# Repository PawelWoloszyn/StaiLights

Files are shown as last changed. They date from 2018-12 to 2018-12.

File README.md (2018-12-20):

Stairs is electronics and programming project of controlling stair lights (led strips attached to bottom side of each step) using arduino nano and tlc5940.
Project contains both electronic schematics and code needed to create such controller, mind that I'm neither professional electronics
circuit designer nor software developer therefore both code and schematics might be adjusted to benefit your own implication.

Right now the device is under development and will remain in this state until implemented in real which is going to allow it's
long term testing and proof it's reliability. In this moment it only serves presentation purpose.

How does it work???
Arduino Nano controlls two TLC5940 controllers which are basicaly 16 channel PWM controller (each chip). PWM signal is inverted and used to drive MOSFET tranzistors which are responsible for regulating the current running through led strips. In order to automate this device DS1307 RTC is used. Thanks to this, device will only be switched on within specified period of time which is calculated by Dusk2Dawn library, lights are triggered by two PIR sensors one upstairs and one downstairs but there are plenty enough spare pins on Arduino nano to use other type of sesnor. Project also allows to externaly regulate device's parameters using microswitch buttons and potentiometer. 

Questions that might bother you:

* What do you need for logical inverters?
- TLC5940 cannot be connected directly to MOSFETS in this project due to it's 0 based logic, of course they could be driven with inverted logic but because of the way tlc functions, you wouldn't be able to completely shut down the lights.

* On schematic you started connecting TLC pins starting from output 2 not 0 why?
- It's because I bought one chip from second hand with one pin missing. Therefore I skipped pin0 and pin1(missing).

Future improvements:
* Definitely chaging DS1307 to DS3231 in order to gain benefits of having alarm clock function in real time clock, which could later on be used to     wake up arduino from sleep mode.
* Reworking board design to decrease it's dimensions, would probably make a 2 sided SMD PCB.

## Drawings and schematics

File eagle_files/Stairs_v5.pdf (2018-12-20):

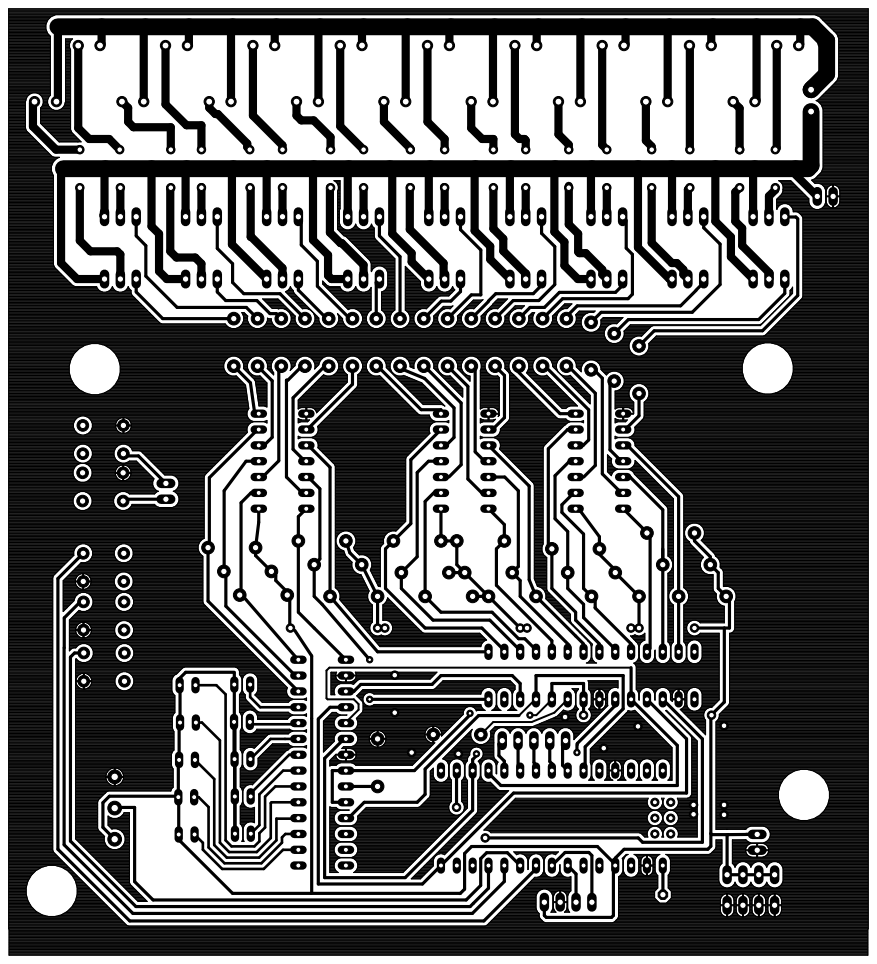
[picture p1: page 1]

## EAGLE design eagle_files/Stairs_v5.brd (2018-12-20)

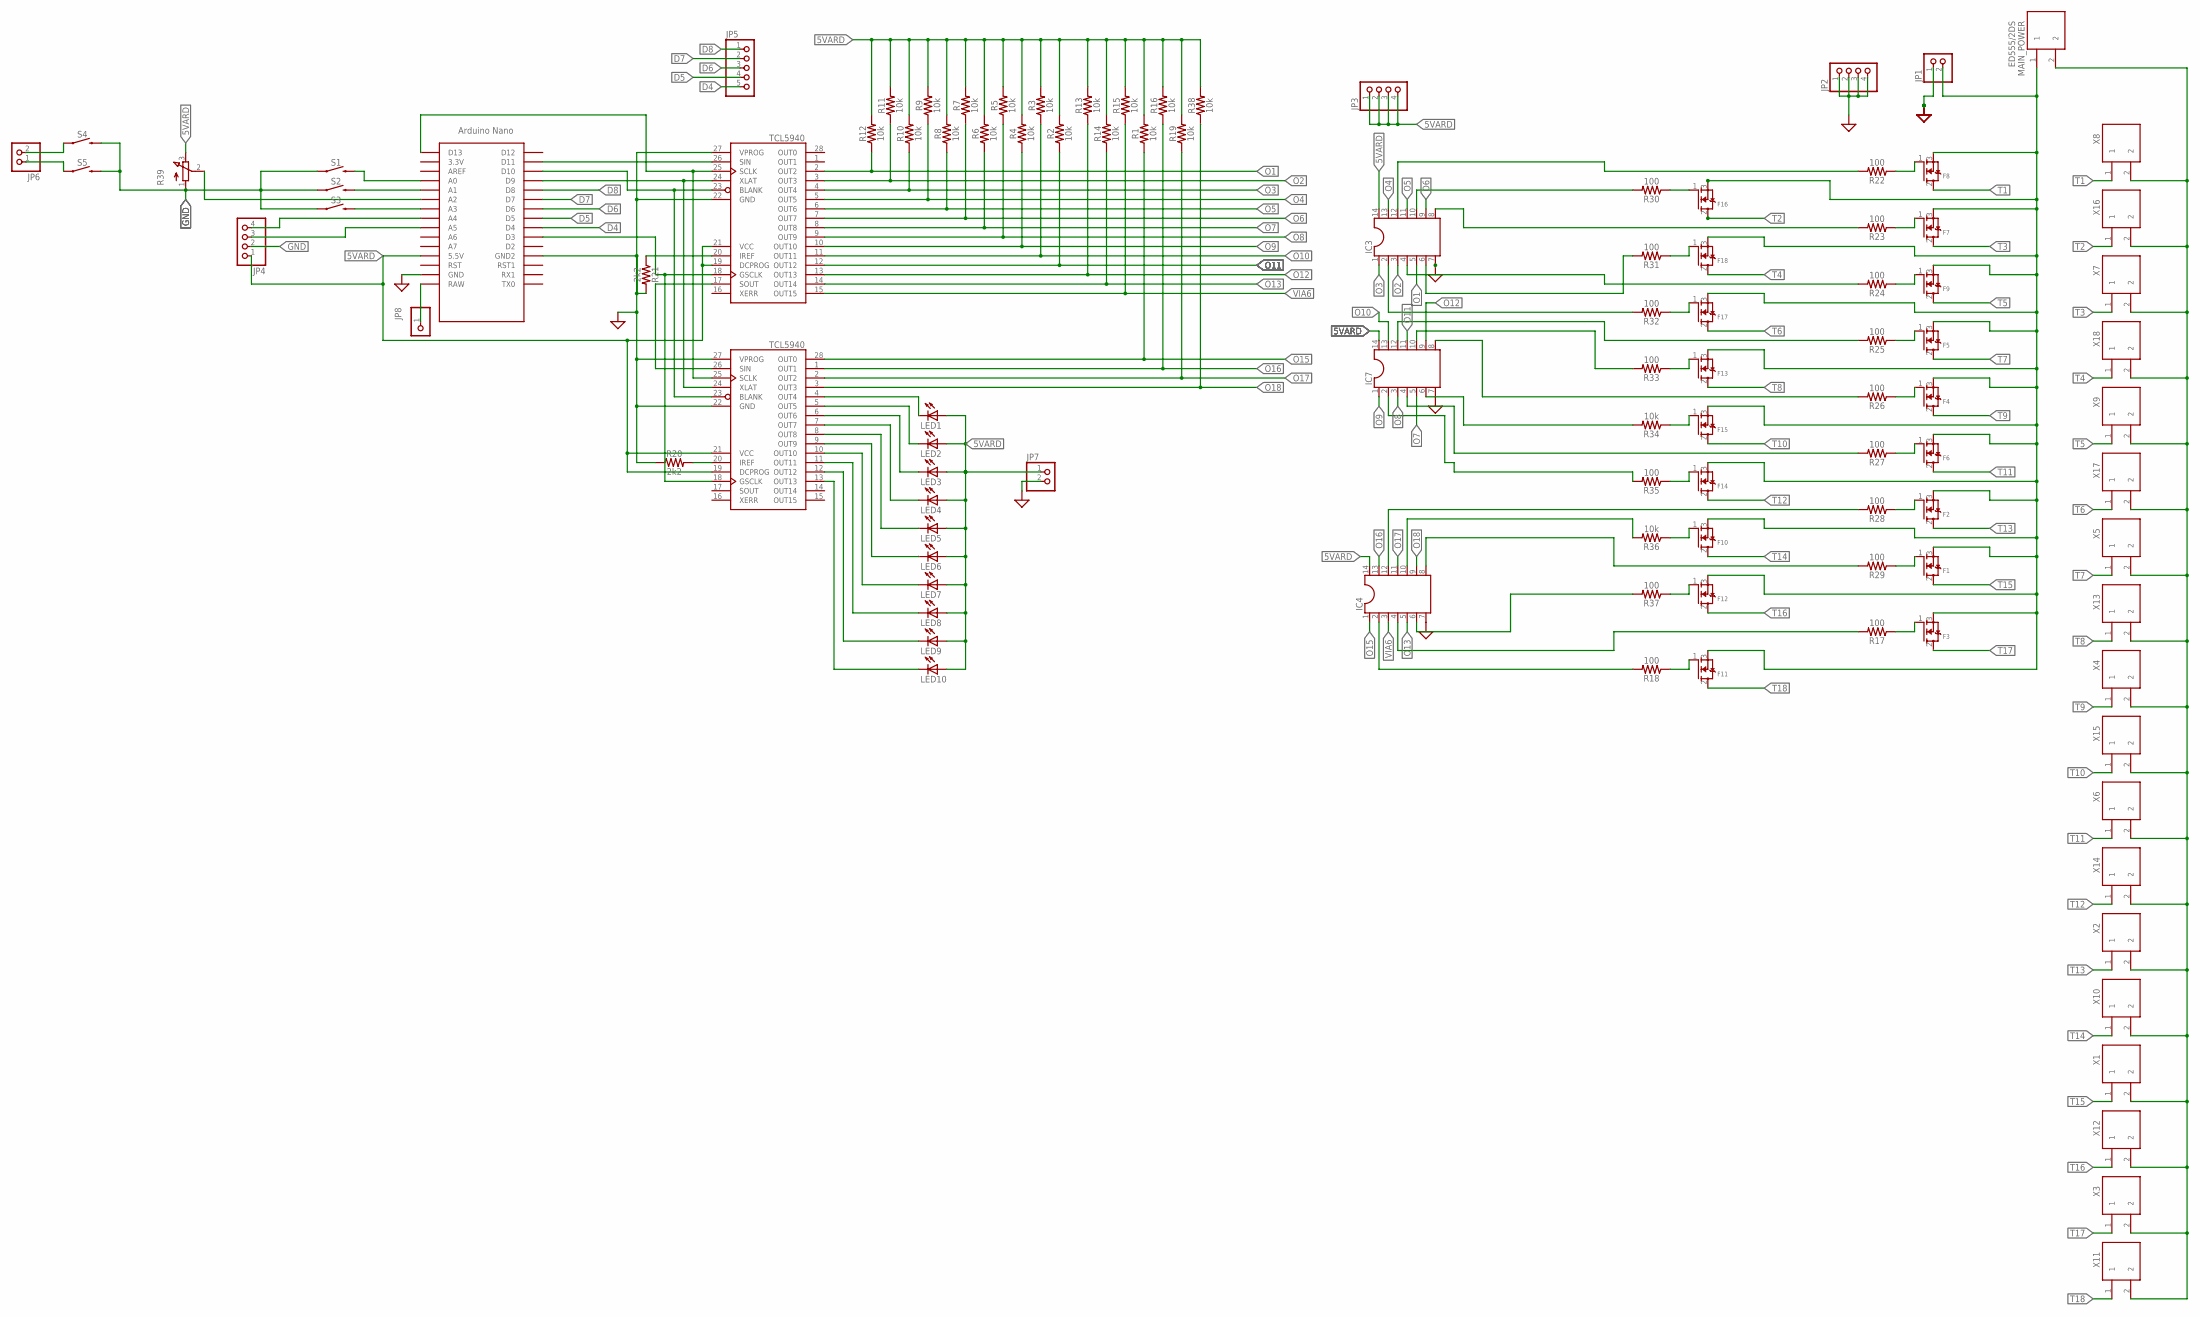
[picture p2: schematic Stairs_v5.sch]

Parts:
F1, F2, F3, F4, F5, F6, F7, F8, F9, F10, F11, F12, F13, F14, F15, F16, F17, F18: MOSFET-NGDS_TO220V; TO220V
IC1, IC2: TCL5940; DIP28
IC3, IC4, IC7: DIL14S; SOCKET-14
JP1, JP6, JP7: PINHD-1X2; 1X02
JP2, JP3, JP4: PINHD-1X4; 1X04
JP5: PINHD-1X5; 1X05
JP8: PINHD-1X1; 1X01
LED1, LED2, LED3, LED4, LED5, LED6, LED7, LED8, LED9, LED10: LEDSFH482; SFH482
MAIN_POWER: ED555/2DS
R1, R2, R3, R4, R5, R6, R7, R8, R9, R10, R11, R12, R13, R14, R15, R16, R19, R34, R36, R38: 10k; AXIAL-0.3-KIT
R17, R18, R22, R23, R24, R25, R26, R27, R28, R29, R30, R31, R32, R33, R35, R37: 100; AXIAL-0.3-KIT
R20, R21: 2k2; AXIAL-0.3-KIT
R39: 3RP/1610N
S1, S2, S3, S4, S5: MOMENTARY-SWITCH-SPST-PTH-6.0MM; TACTILE_SWITCH_PTH_6.0MM
U$1: NANO
X1, X2, X3, X4, X5, X6, X7, X8, X9, X10, X11, X12, X13, X14, X15, X16, X17, X18: ED555/2DS

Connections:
5VARD: IC1.19 (DCPROG), IC1.21 (VCC), IC2.19 (DCPROG), IC2.21 (VCC), IC3.14, IC4.14, IC7.14, JP3.1, JP3.2, JP3.3, JP3.4, JP4.1, JP7.1, LED1.A, LED2.A, LED3.A, LED4.A, LED5.A, LED6.A, LED7.A, LED8.A, LED9.A, LED10.A, R1.P$2 (2), R2.P$2 (2), R3.P$2 (2), R4.P$2 (2), R5.P$2 (2), R6.P$2 (2), R7.P$2 (2), R8.P$2 (2), R9.P$2 (2), R10.P$2 (2), R11.P$2 (2), R12.P$2 (2), R13.P$2 (2), R14.P$2 (2), R15.P$2 (2), R16.P$2 (2), R19.P$2 (2), R38.P$2 (2), R39.3 (E), U$1.5V (5.5V)
D4: JP5.5, U$1.D4
D5: JP5.4, U$1.D5
D6: JP5.3, U$1.D6
D7: JP5.2, U$1.D7
D8: JP5.1, U$1.D8
GND: IC1.22 (GND), IC1.27 (VPROG), IC2.22 (GND), IC2.27 (VPROG), IC3.7, IC4.7, IC7.7, JP1.1, JP2.1, JP2.2, JP2.3, JP2.4, JP4.2, JP7.2, R20.P$1 (1), R21.P$2 (2), R39.1 (A), S1.1, S2.1, S3.1, S4.3 (2), S5.3 (2), U$1.GND, U$1.GND1 (GND2)
unnamed: IC2.4 (OUT4), LED1.K (C)
unnamed: JP8.1, U$1.RAW
unnamed: IC1.25 (SCLK), IC2.25 (SCLK), U$1.D13
unnamed: IC1.24 (XLAT), IC2.24 (XLAT), U$1.D9
unnamed: IC2.5 (OUT5), LED2.K (C)
unnamed: JP6.2, S4.1
unnamed: S1.3 (2), U$1.A0
unnamed: IC1.17 (SOUT), IC2.26 (SIN)
unnamed: IC1.20 (IREF), R21.P$1 (1)
unnamed: IC2.20 (IREF), R20.P$2 (2)
unnamed: F7.1 (G), R23.P$1 (1)
unnamed: IC1.18 (GSCLK), IC2.18 (GSCLK), U$1.D3
unnamed: S2.3 (2), U$1.A1
unnamed: R39.2 (S), U$1.A2
unnamed: F9.1 (G), R24.P$1 (1)
unnamed: S3.3 (2), U$1.A3
unnamed: JP4.4, U$1.A4
unnamed: F5.1 (G), R25.P$1 (1)
unnamed: JP4.3, U$1.A5
unnamed: F4.1 (G), R26.P$1 (1)
unnamed: JP6.1, S5.1
unnamed: F8.1 (G), R22.P$1 (1)
unnamed: IC2.6 (OUT6), LED3.K (C)
unnamed: F6.1 (G), R27.P$1 (1)
unnamed: IC2.7 (OUT7), LED4.K (C)
unnamed: IC2.8 (OUT8), LED5.K (C)
unnamed: F2.1 (G), R28.P$1 (1)
unnamed: IC2.9 (OUT9), LED6.K (C)
unnamed: IC2.10 (OUT10), LED7.K (C)
unnamed: F1.1 (G), R29.P$1 (1)
unnamed: IC2.11 (OUT11), LED8.K (C)
unnamed: IC2.12 (OUT12), LED9.K (C)
unnamed: IC2.13 (OUT13), LED10.K (C)
unnamed: F16.1 (G), R30.P$1 (1)
unnamed: F18.1 (G), R31.P$1 (1)
unnamed: F17.1 (G), R32.P$1 (1)
unnamed: F13.1 (G), R33.P$1 (1)
unnamed: F15.1 (G), R34.P$1 (1)
unnamed: F14.1 (G), R35.P$1 (1)
unnamed: F10.1 (G), R36.P$1 (1)
unnamed: F12.1 (G), R37.P$1 (1)
unnamed: IC3.12, R22.P$2 (2)
unnamed: IC3.8, R23.P$2 (2)
unnamed: IC3.4, R24.P$2 (2)
unnamed: IC7.10, R33.P$2 (2)
unnamed: IC3.10, R30.P$2 (2)
unnamed: IC3.6, R31.P$2 (2)
unnamed: IC3.2, R32.P$2 (2)
unnamed: IC7.12, R25.P$2 (2)
unnamed: IC7.8, R26.P$2 (2)
unnamed: IC7.4, R27.P$2 (2)
unnamed: IC4.12, R28.P$2 (2)
unnamed: IC4.8, R29.P$2 (2)
unnamed: IC7.6, R34.P$2 (2)
unnamed: IC4.10, R36.P$2 (2)
unnamed: IC7.2, R35.P$2 (2)
unnamed: IC4.6, R37.P$2 (2)
unnamed: F3.1 (G), R17.P$1 (1)
unnamed: IC4.4, R17.P$2 (2)
unnamed: F11.1 (G), R18.P$1 (1)
unnamed: IC4.2, R18.P$2 (2)
O1: IC1.2 (OUT2), IC3.5, R12.P$1 (1)
O2: IC1.3 (OUT3), IC3.3, R11.P$1 (1)
O3: IC1.4 (OUT4), IC3.1, R10.P$1 (1)
O4: IC1.5 (OUT5), IC3.13, R9.P$1 (1)
O5: IC1.6 (OUT6), IC3.11, R8.P$1 (1)
O6: IC1.7 (OUT7), IC3.9, R7.P$1 (1)
O7: IC1.8 (OUT8), IC7.5, R6.P$1 (1)
O8: IC1.9 (OUT9), IC7.3, R5.P$1 (1)
O9: IC1.10 (OUT10), IC7.1, R4.P$1 (1)
O10: IC1.11 (OUT11), IC7.13, R3.P$1 (1)
O11: IC1.12 (OUT12), IC7.11, R2.P$1 (1)
O12: IC1.13 (OUT13), IC7.9, R13.P$1 (1)
O13: IC1.14 (OUT14), IC4.5, R14.P$1 (1)
O15: IC2.28 (OUT0), IC4.1, R1.P$1 (1)
O16: IC2.1 (OUT1), IC4.13, R16.P$1 (1)
O17: IC2.2 (OUT2), IC4.11, R19.P$1 (1)
O18: IC2.3 (OUT3), IC4.9, R38.P$1 (1)
POWER+: MAIN_POWER.2, X1.2, X2.2, X3.2, X4.2, X5.2, X6.2, X7.2, X8.2, X9.2, X10.2, X11.2, X12.2, X13.2, X14.2, X15.2, X16.2, X17.2, X18.2
POWER-: F1.3 (S), F2.3 (S), F3.3 (S), F4.3 (S), F5.3 (S), F6.3 (S), F7.3 (S), F8.3 (S), F9.3 (S), F10.3 (S), F11.3 (S), F12.3 (S), F13.3 (S), F14.3 (S), F15.3 (S), F16.3 (S), F17.3 (S), F18.3 (S), JP1.2, MAIN_POWER.1
T1: F8.2 (D), X8.1
T2: F16.2 (D), X16.1
T3: F7.2 (D), X7.1
T4: F18.2 (D), X18.1
T5: F9.2 (D), X9.1
T6: F17.2 (D), X17.1
T7: F5.2 (D), X5.1
T8: F13.2 (D), X13.1
T9: F4.2 (D), X4.1
T10: F15.2 (D), X15.1
T11: F6.2 (D), X6.1
T12: F14.2 (D), X14.1
T13: F2.2 (D), X2.1
T14: F10.2 (D), X10.1
T15: F1.2 (D), X1.1
T16: F12.2 (D), X12.1
T17: F3.2 (D), X3.1
T18: F11.2 (D), X11.1
VIA4: IC1.26 (SIN), U$1.D11
VIA6: IC1.15 (OUT15), IC4.3, R15.P$1 (1)
VIAXX: IC1.23 (BLANK), IC2.23 (BLANK), U$1.D10

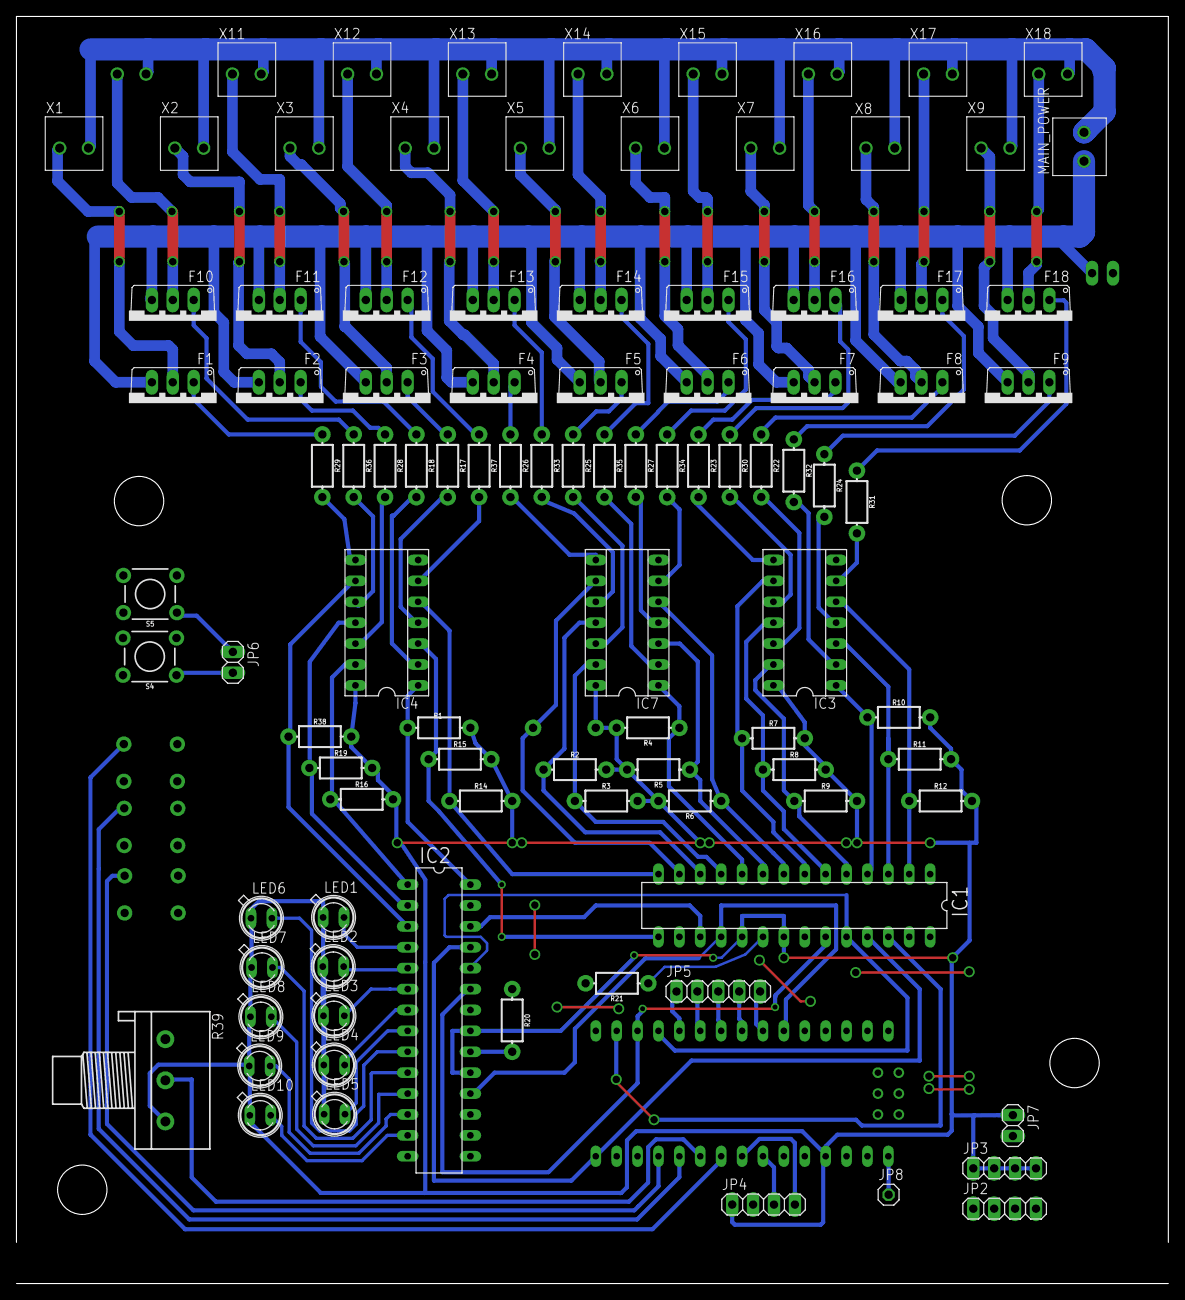
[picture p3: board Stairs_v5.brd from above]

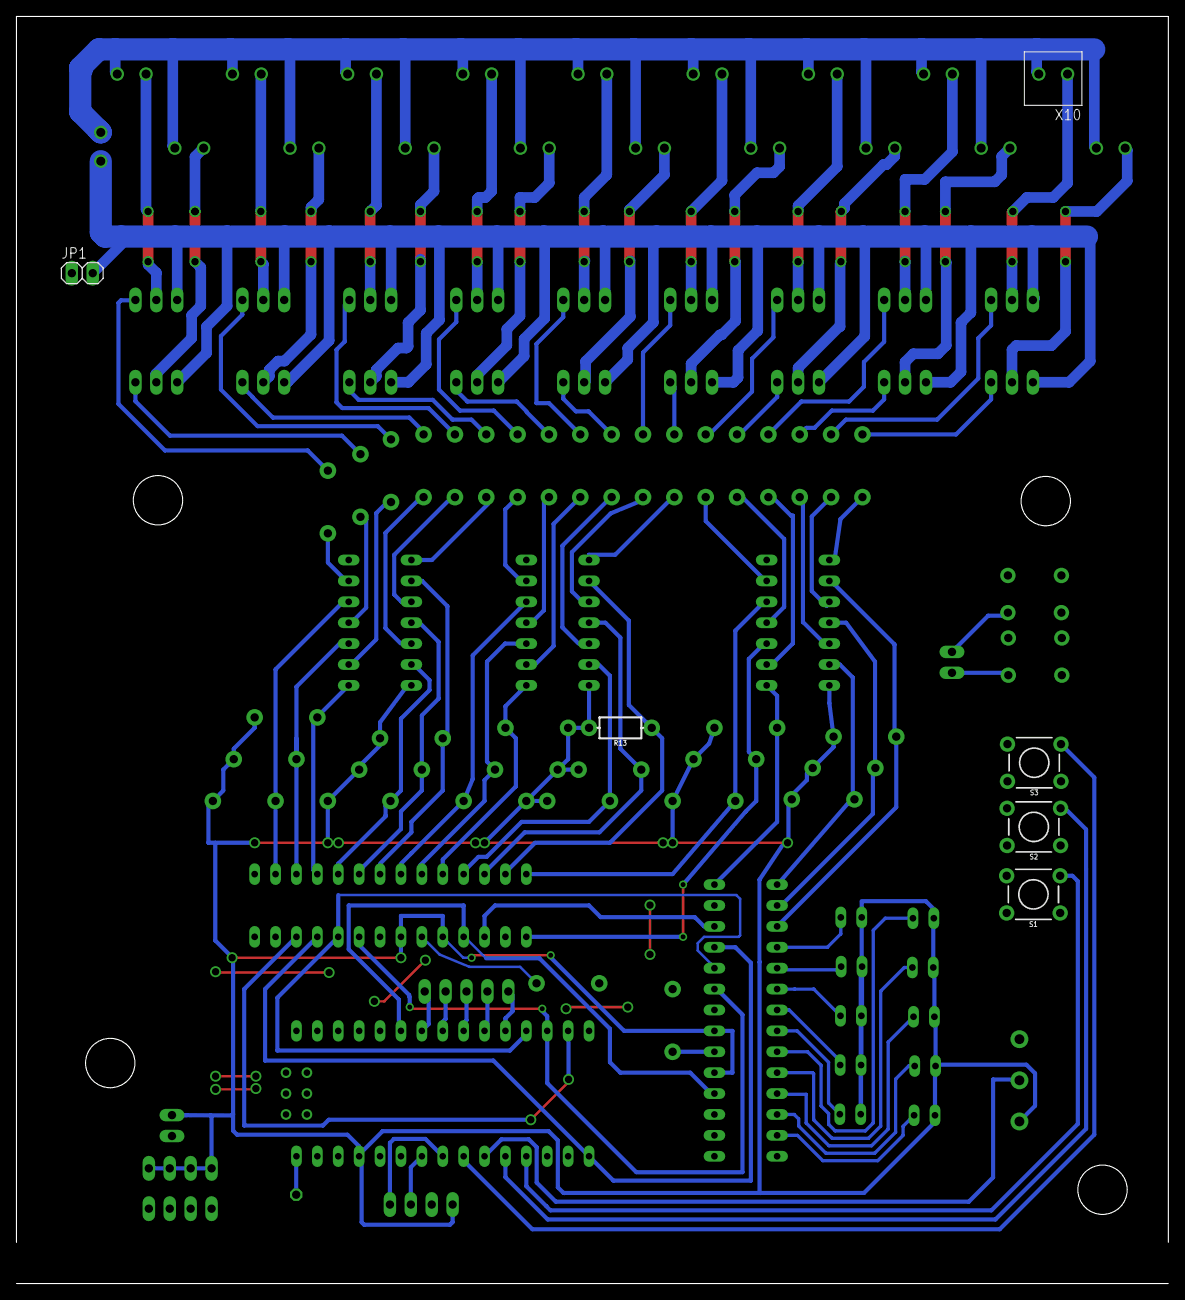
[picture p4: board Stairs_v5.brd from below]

Board: 2 copper layers, 140.0 x 154.0 mm, 105 parts (6 on the bottom side), 108 nets.

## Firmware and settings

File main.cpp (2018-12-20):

#include <Arduino.h>
#include <Wire.h>
#include <TimeLib.h>
#include <DS1307RTC.h>
#include <Dusk2Dawn.h>
#include <TomorrowDate.h>
#include <StairsInteract.h>

//RTC connections SDA -> A4 SCL -> A5
#define ERROR_LED 8 // connect red diode to indicate errors
#define SENSOR_UPSTAIRS 7
#define SENSOR_DOWNSTAIRS 6
#define DOWNSTAIRS_DETECTION 1
#define UPSTAIRS_DETECTION 2
#define NO_DETECTION 0
#define ON 0

//change this for different location
#define XCORDS 50.039968
#define YCORDS 19.974380
#define UTC_OFFSET 1 // utc offset for your time zone

boolean daySaving = false; // set true if DST is in effect

boolean running = false;
Dusk2Dawn location(XCORDS, YCORDS, UTC_OFFSET);
int turnOnTime;
int turnOffTime;
int buffer[3];

StairsInteract stairs;

tmElements_t tm;

boolean setCurrentDate(){
	if(RTC.read(tm)) {
		buffer[0] = 1970 + tm.Year;
		buffer[1] = tm.Month;
		buffer[2] = tm.Day;
		return true;
	}
	return false;
}

void setOnTime(){
	if(setCurrentDate()) {
		int locationSunset = location.sunset(buffer[0], buffer[1], buffer[2], daySaving);
		if(locationSunset >= 0 && locationSunset <= 1440) {
			turnOnTime = locationSunset;
		}
	}
}

void setOffTime(){
	if(setCurrentDate()) {
		int locationSunrise = location.sunrise(buffer[0], buffer[1], buffer[2], daySaving);
		if(locationSunrise >= 0 && locationSunrise <= 1440) {
			turnOffTime = locationSunrise;
		}
	}
}

void setOffTimeTomorrow(){
	if(setCurrentDate()) {
		TomorrowDate date((buffer[0]-2000), buffer[1], buffer[2]);
		int locationSunrise = location.sunrise((2000 + date.gety()), date.getm(), date.getd(), daySaving);
		if(locationSunrise >= 0 && locationSunrise <= 1440) {
			turnOffTime = locationSunrise;
		}
	}
}

int getCurrentTime(){
	return ((tm.Hour*60) + tm.Minute);
}

//returns true when it should be dark outside
boolean check(){
	if(RTC.read(tm)) {
		int currentTime = getCurrentTime();
		if(currentTime > turnOnTime || currentTime < turnOffTime) {
			return true;
		}else{
			return false;
		}
	}else{
		Serial.println("Problem with RTC timer!");
		if (RTC.chipPresent()) {
			Serial.println("The DS1307 is stopped.  Please run the SetTime");
		} else {
			Serial.println("DS1307 read error!  Please check the circuitry.");
		}
		return false;
	}
	return false;
}

int checkSensors(){
	if(digitalRead(SENSOR_DOWNSTAIRS) == ON)
		return DOWNSTAIRS_DETECTION;
	else if(digitalRead(SENSOR_UPSTAIRS) == ON)
		return UPSTAIRS_DETECTION;
	else
		return NO_DETECTION;
}
/////////////////////////////// SETUP /////////////////////////////////////////
void setup() {
	//setup sensors
	pinMode(SENSOR_DOWNSTAIRS, INPUT_PULLUP);
	pinMode(SENSOR_UPSTAIRS, INPUT_PULLUP);
	pinMode(ERROR_LED, OUTPUT);
	stairs.initialize();
	//setup buttons
	Serial.begin(9600);
	delay(200);
	// wait for RTC data
	while(!RTC.read(tm)) {
		Serial.println("Problem with RTC data");
		delay(1000);
	}
	delay(200);
	setOnTime();
	setOffTime();
	running = check();
	if(running && (getCurrentTime() > turnOnTime)) {
		setOffTimeTomorrow();
	}
}
/////////////////////// MAIN loop()////////////////////////////////
void loop() {
	while(running) {
		if(!check()) {
			setOnTime();
			running = false;
			break;
		}
		if(checkSensors() == DOWNSTAIRS_DETECTION) {
			// Serial.println("Downstairs detection");
			if(stairs.turnLights(true, true)) {
				unsigned long timeOff = millis() + stairs.getTimeOn();
				// Serial.println("All stair ligts are up now");
				while(true) {
					if(checkSensors() != NO_DETECTION) {
						// if there was yet another detection reset the timer
						// Serial.println("Timer reset invoked");
						timeOff = millis() + stairs.getTimeOn();
					}
					if(millis() > timeOff) {
						// Serial.println("We are done here turn it off now");
						if(stairs.turnLights(false, true))
							break;
					}
				}

			}
		} else if(checkSensors() == UPSTAIRS_DETECTION) {
			// Serial.println("Upstairs detection");
			if(stairs.turnLights(true, false)) {
				unsigned long timeOff = millis() + stairs.getTimeOn();
				// Serial.println("All stair ligts are up now");
				while(true) {
					if(checkSensors() != NO_DETECTION) {
						// if there was yet another detection reset the timer
						// Serial.println("Timer reset invoked");
						timeOff = millis() + stairs.getTimeOn();
					}
					if(millis() > timeOff) {
						// Serial.println("We are done here turn it off now");
						if(stairs.turnLights(false, false))
							break;
					}
				}
			}
		}
		delay(1000); // a temporary console anti-spam
	}


	while(!running) {
		if(check()) {
			setOffTimeTomorrow();
			running = true;
			break;
		}
		delay(10000);
	}
}

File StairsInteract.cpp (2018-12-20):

#include "Arduino.h"
#include "StairsInteract.h"
#include <Tlc5940.h>
#include <tlc_fades.h>
#include <Bounce2.h>
#include <EEPROM.h>

#define BUTTON0 A0  // button responsible for setting change option/save
#define BUTTON1 A1 // button responsible for enter/back
#define BUTTON2 A3 // button responsible for exit
#define POTENTIOMETER_PIN A2
#define BRIGHTNESS_MULTIPLIER 4 // leave it at 4
#define ALL_ON_TIME_MULTIPLIER 13 // time regulation multiplier
#define FADE_TIME_MULTIPLIER 3
#define STEP_DELAY_MULTIPLIER 2
#define BUZZER 5
#define START_OUTPUT 2
#define STOP_OUTPUT 19
#define STEP_AMOUNT ((STOP_OUTPUT - START_OUTPUT) +1)
#define ON 0
#define OFF 1

int parameters[5];// = {1500, 5000, 2000, 1000, 0};

Bounce button0 = Bounce();
Bounce button1 = Bounce();
Bounce button2 = Bounce();

// CONSTRUCTOR
StairsInteract::StairsInteract(){
}
int StairsInteract::getTimeOn(){
	return parameters[1];
}
int StairsInteract::getFadeTime(){
	return parameters[2];
}

int StairsInteract::getStepDelay(){
	return parameters[3];
}

void StairsInteract::loadEepromValues(){
	for(int i = 0; i < 4; i++) {
		// value 255 is considered as not defined value
		if(EEPROM.read(i) != 255) {
			parameters[i] = EEPROM.read(i);
		}
	}
}

void StairsInteract::initialize(){
	Serial.begin(9600);
	Tlc.init();
	// these are default values:
	parameters[0]= 1500; // maxBrightness
	parameters[1]= 5000; // timeOn
	parameters[2]= 2000; // fadeTime
	parameters[3]= 1000; // stepDelay
	parameters[4]= 0;		 // minBrightness
	pinMode(BUTTON0, INPUT_PULLUP);
	pinMode(BUTTON1, INPUT_PULLUP);
	pinMode(BUTTON2, INPUT_PULLUP);
	pinMode(BUZZER, OUTPUT);
	button0.attach(BUTTON0);
	button0.interval(5);
	button1.attach(BUTTON1);
	button1.interval(5);
	button2.attach(BUTTON2);
	button2.interval(5);
	loadEepromValues();
}

void StairsInteract::updateMyButtons(){
	button0.update();
	button1.update();
	button2.update();
}

int StairsInteract::potentiometerRead(){
	return analogRead(POTENTIOMETER_PIN);
}

void StairsInteract::beep(int amount){
	int x = amount + 1;
	while(x >0) {
		digitalWrite(BUZZER, ON);
		delay(100);
		digitalWrite(BUZZER, OFF);
		delay(100);
		x--;
	}
}

void StairsInteract::longBeep(){
	digitalWrite(BUZZER, ON);
	delay(300);
	digitalWrite(BUZZER, OFF);
}

int StairsInteract::adjustValue(int arg, int multiplier){
	Tlc.clear();
	Tlc.update();
	while(true) {
		int value = potentiometerRead() * multiplier;
		// visual presentaton for max brihtness
		if(arg == 0) {
			Tlc.setAll(value);
			Tlc.update();
		}
		updateMyButtons();
		if(button0.fell()) {
			//settings were saved
			Tlc.clear();
			Tlc.update();
			int valueToSave = value/(multiplier * 4);
			//255 is considered as not defined value
			//it causes very insignificant precision loss
			if(valueToSave == 255)
				valueToSave = 254;
			EEPROM.write(arg, valueToSave);
			parameters[arg] = value;
			return 0;
		}
		if(button1.fell()) {
			// back to 1st level
			Tlc.clear();
			Tlc.update();
			return 1;
		}
		if(button2.fell()) {
			// exit settings menu completely
			Tlc.clear();
			Tlc.update();
			return 2;
		}
	}
}
//MENU LAYERS
int StairsInteract::menuLayerTwo(int arg){
	// BRIGHTNESS settings
	if(arg == 0) {
		return adjustValue(arg, BRIGHTNESS_MULTIPLIER);
	}
	// TIME FOR ALL TO BE ON SETTINGS
	else if(arg == 1) {
		return adjustValue(arg, ALL_ON_TIME_MULTIPLIER);
	}
	// FADE TIME SETTINGS
	else if(arg == 2) {
		return adjustValue(arg, FADE_TIME_MULTIPLIER);
	}
	// STEP DELAY SETTINGS
	else if(arg == 3) {
		return adjustValue(arg, STEP_DELAY_MULTIPLIER);
	}
	else return 2;     // Exit menus completely
}

void StairsInteract::menuLayerOne(){
	longBeep();
	int currentPosition = 0;
	while(true) {
		updateMyButtons();
		// reaction 1  CHANGE VALUE TO ADJUST
		if(button0.fell()) {
			if(currentPosition < 3)
				currentPosition++;
			else
				currentPosition = 0;
			beep(currentPosition);
		}
		// reaction 2  GO TO SECOND LAYER
		if(button1.fell()) {
			longBeep();
			beep(currentPosition);
			if(currentPosition >= 0 && currentPosition < 4) {
				int response = menuLayerTwo(currentPosition);
				if(response == 0) {
					// settings were saved
					longBeep();
					break;
				}else if(response == 1) {
					// you backed to first level menu
					beep(currentPosition);
				}else if(response == 2) {
					//you clicked exit from 2nd level settingsMenu
					longBeep();
					break;
				}
			}
		}
		//reaction 3  EXIT
		if(button2.fell()) {
			longBeep();
			break;
		}
	}
}

// main function for controlling
boolean StairsInteract::turnLights(boolean turnOn, boolean rising){
	int startOuput = (rising ? START_OUTPUT : STOP_OUTPUT);
	int startValue = (turnOn ? parameters[4] : parameters[0]);
	int stopValue = (turnOn ? parameters[0] : parameters[4]);
	int i, j;
	Serial.println("test1");
	for(i = startOuput, j = 0; j < STEP_AMOUNT; j++) {
		if(!tlc_isFading(i)) {
			unsigned long time = millis();
			tlc_addFade(i, startValue, stopValue,
			            time + (parameters[3] * j),
			            (time + (parameters[3] * j) + parameters[2] ));
		} else {
			return false;
		}

		if(rising) {
			i++;
		} else {
			i--;
		}
	}
	while(tlc_updateFades());
	// if statement below has to be added due to bug which doesn't shut down last segment
	if(!turnOn){
		if(rising){
			Tlc.set(STOP_OUTPUT,0);
			Tlc.update();
		}else{
			Tlc.set(START_OUTPUT, 0);
			Tlc.update();
		}
	}
	return true;
}

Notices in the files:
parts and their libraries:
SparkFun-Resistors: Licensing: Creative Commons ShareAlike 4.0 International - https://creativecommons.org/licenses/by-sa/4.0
